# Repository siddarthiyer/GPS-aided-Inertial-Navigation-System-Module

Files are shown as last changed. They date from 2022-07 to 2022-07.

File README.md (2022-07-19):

# GPS-aided Inertial Navigation System Module (In Progress)

* MCU: STM32F103C8T6
* Communication Protocol: CAN
* Features: Pitch, Roll, Yaw, Direction, Latitude, Longitude, Temperature, Altitude, Pressure 

<hr>

<h3>CAN Frame </h3>
(Based on CANopen)

Upper 6 bits - Module ID - max 0x3F </br>
Lower 5 bits - Command ID - max 0x1F</br>
CAN ID = (Module ID << 5) | Command ID</br>
Default Module ID : 0x200 (Standard)

| CMD_ID | Name | Sender  | Signals | Start byte | Signal Type | Bits |
| --- | -----| --- | ---  | --- | --- |--- |
| `0x001` | Heartbeat | Module  | Latitude, Longitude  | 0, 4  | IEEE 754 Float, IEEE 754 Float | 32, 32 |

<hr>

<h3>Sensors: </h3>

* MPU-9250
  * 9-axis MEMS sensor
  * Pinout:
    - PB11: SDA
    - PB10: SCL
  * Communication Protocol: I2C
  
* NEO-6M
  * GPS Module
  * Pinout:
    - PA3: TX
    - PA2: RX
  * Communication Protocol: UART
 
* BMP180
  * Barometric Pressure/Temperature/Altitude Sensor
  * Pinout:
    - PB7: SDA
    - PB6: SCL
  * Communication Protocol: I2C

<hr>

<h3>PCB Design </h3>



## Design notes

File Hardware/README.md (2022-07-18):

# GPS-aided Inertial Navigation System PCB





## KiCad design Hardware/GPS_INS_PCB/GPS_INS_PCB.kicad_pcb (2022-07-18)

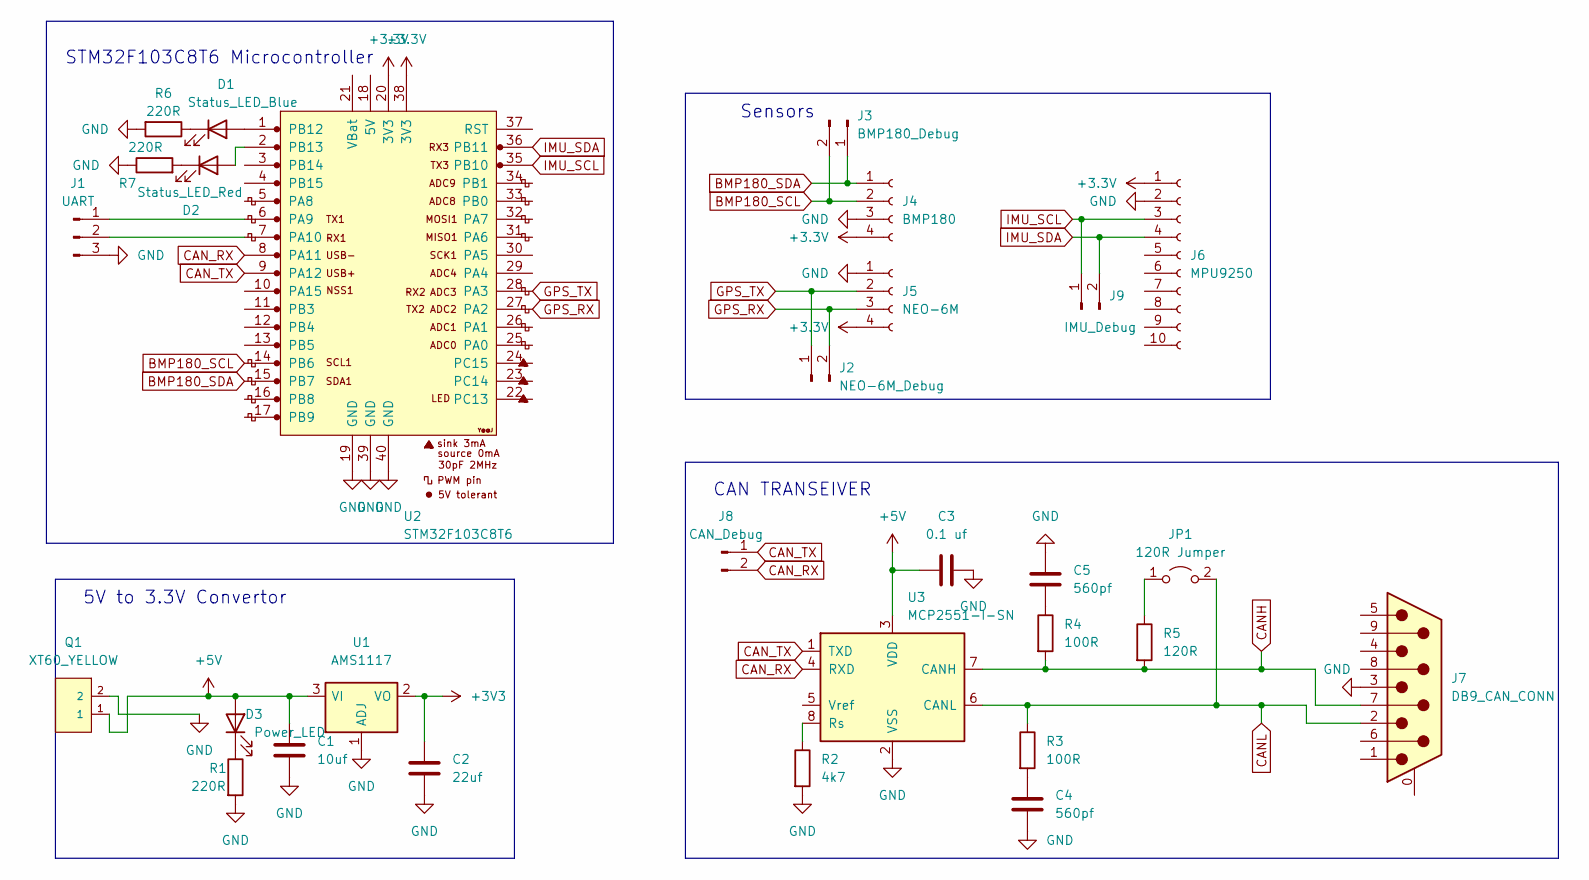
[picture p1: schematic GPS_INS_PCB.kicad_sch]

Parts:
C1: 10uf; C_0805_2012Metric_Pad1.18x1.45mm_HandSolder
C2: 22uf; CP_EIA-1608-08_AVX-J_Pad1.25x1.05mm_HandSolder
C3: 0.1 uf; C_0805_2012Metric_Pad1.18x1.45mm_HandSolder
C4, C5: 560pf; C_0805_2012Metric_Pad1.18x1.45mm_HandSolder
D1: Status_LED_Blue; LED_D5.0mm
D2: Status_LED_Red; LED_D5.0mm
D3: Power_LED; LED_D5.0mm
J1: UART; PinHeader_1x03_P2.54mm_Vertical
J2: NEO-6M_Debug; PinHeader_1x02_P2.54mm_Vertical
J3: BMP180_Debug; PinHeader_1x02_P2.54mm_Vertical
J4: BMP180; PinSocket_1x04_P2.54mm_Vertical
J5: NEO-6M; PinSocket_1x04_P2.54mm_Vertical
J6: MPU9250; PinSocket_1x10_P2.54mm_Vertical
J7: DB9_CAN_CONN; DSUB-9_Male_Horizontal_P2.77x2.84mm_EdgePinOffset4.94mm_Hou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
J8: CAN_Debug; PinHeader_1x02_P2.54mm_Vertical
J9: IMU_Debug; PinHeader_1x02_P2.54mm_Vertical
JP1: 120R Jumper; PinHeader_1x02_P2.54mm_Vertical
Q1: XT60_YELLOW; AMASS_XT60PB-M; PARTREV 1.2
R1, R6, R7: 220R; R_0805_2012Metric_Pad1.20x1.40mm_HandSolder
R2: 4k7; R_0805_2012Metric_Pad1.20x1.40mm_HandSolder
R3, R4: 100R; R_0805_2012Metric_Pad1.20x1.40mm_HandSolder
R5: 120R; R_0805_2012Metric_Pad1.20x1.40mm_HandSolder
U1: AMS1117; SOT-223-3_TabPin2
U2: STM32F103C8T6; YAAJ_BluePill_1
U3: MCP2551-I-SN; SOIC-8_3.9x4.9mm_P1.27mm

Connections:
+5V: C1.1, C3.1, D3.2 (A), Q1.1, U1.3 (VI), U3.3 (VDD)
BMP180_SCL: J3.2, J4.2, U2.14 (PB6)
BMP180_SDA: J3.1, J4.1, U2.15 (PB7)
CANH: J7.7, R4.2, R5.2, U3.7 (CANH)
CANL: J7.2, JP1.2 (B), R3.1, U3.6 (CANL); also elsewhere on the board
CAN_RX: J8.2, U2.8 (PA11), U3.4 (RXD)
CAN_TX: J8.1, U2.9 (PA12), U3.1 (TXD)
GND: C1.2, C2.2, C3.2, C4.2, C5.1, J1.3, J4.3, J5.1, J6.2, J7.3, Q1.2, R1.2, R2.2, R6.2, R7.1, U1.1 (ADJ), U2.19 (GND), U2.39 (GND), U2.40 (GND), U3.2 (VSS)
GPS_RX: J2.2, J5.3, U2.27 (PA2)
GPS_TX: J2.1, J5.2, U2.28 (PA3)
IMU_SCL: J6.3, J9.1, U2.35 (PB10)
IMU_SDA: J6.4, J9.2, U2.36 (PB11)
unnamed: C4.1, R3.2
unnamed: C5.2, R4.1
unnamed: D1.1 (K), R6.1
unnamed: D2.1 (K), R7.2
unnamed: D3.1 (K), R1.1
unnamed: J1.1, U2.6 (PA9)
unnamed: J1.2, U2.7 (PA10)
unnamed 19: JP1.1 (A), R5.1; also elsewhere on the board
unnamed: R2.1, U3.8 (Rs)
unnamed: D1.2 (A), U2.1 (PB12)
unnamed: D2.2 (A), U2.2 (PB13)

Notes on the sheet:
5V to 3.3V Convertor
Sensors
CAN TRANSEIVER
STM32F103C8T6 Microcontroller

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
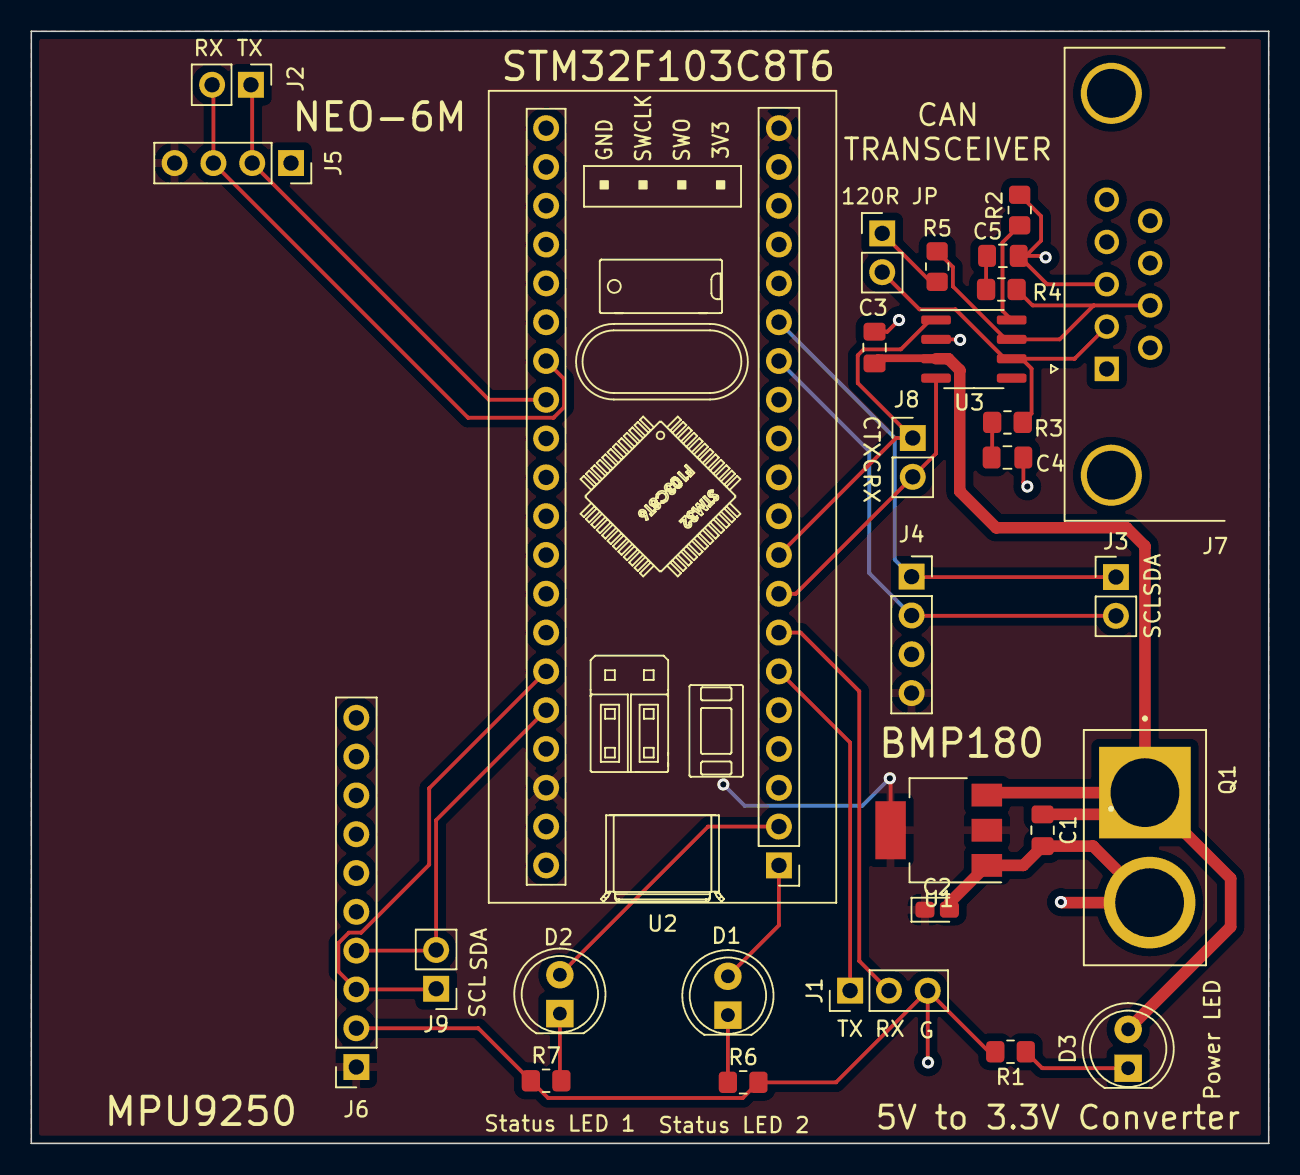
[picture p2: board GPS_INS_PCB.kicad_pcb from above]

Board: 2 copper layers, 81.0 x 72.8 mm, 29 parts (0 on the bottom side), 24 nets.

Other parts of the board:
120R JP: 120R Jumper; PinHeader_1x02_P2.54mm_Vertical

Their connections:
CANL: 120R JP.2 (B); also elsewhere on the board
unnamed 19: 120R JP.1 (A); also elsewhere on the board

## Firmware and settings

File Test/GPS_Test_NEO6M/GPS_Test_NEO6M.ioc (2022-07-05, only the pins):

Mcu.UserName=STM32F103C8Tx
PA10.Signal=USART1_RX
PA13.Signal=SYS_JTMS-SWDIO
PA14.Signal=SYS_JTCK-SWCLK
PA2.Signal=USART2_TX
PA3.Signal=USART2_RX
PA9.Signal=USART1_TX
PD0-OSC_IN.Signal=RCC_OSC_IN
PD1-OSC_OUT.Signal=RCC_OSC_OUT
